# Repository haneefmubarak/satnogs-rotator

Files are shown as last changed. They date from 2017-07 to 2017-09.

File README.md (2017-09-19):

# SatNOGS Rotator

Hardware for SatNOGS Rotator. This repository includes all needed source files for 3D printed (and other) parts of SatNOGS Rotator.

## Documentation

More information can be found in our [documentation](http://satnogs.org/documentation/hardware/), or our [wiki](https://wiki.satnogs.org).

## Repository policy
SatNOGS hardware repositories only track source design files. All needed derivative files (e.g. stl, grb etc) for production are created per release, packaged in an archive and uploaded linked to a  [release](https://gitlab.com/librespacefoundation/satnogs/satnogs-rotator/tags).

Each major release (x.0.0) is branched out of master. Subsequent fixes (minor or not) are commited on those branches and tagged accordingly.

Master branch is most times under active development, so expect things to break. For production ready and previous releases source files check tags and branches.

## Contribute

The main repository lives on [Gitlab](https://gitlab.com/librespacefoundation/satnogs/satnogs-rotator) and all Merge Request should happen there.

## License

&copy; 2014-2015 [Libre Space Foundation](http://librespacefoundation.org).

Licensed under the [CERN OHLv1.2](LICENSE).

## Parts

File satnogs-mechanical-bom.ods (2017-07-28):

Part | Description | Distributor | Qty For 1 Rotator | Price Per Unit Small QNT (euro) | Total Price | Printing Time (min) Per 1 part | Price Per Unit Large QNT (euro) | Total price | Comments | QTY 30 kits
axis_side.stl | Axis side, 3D printed | - | 4 | 0.5 | 2 | 110 | 0.7 | 2.8 |  | 116
switch_endstop_holder.stl | Mount for mechanichal endstop, 3D printed | - | 2 | 0.5 | 1 | 4 | 0.7 | 1.4 |  | 0
ball_bearing_housing.stl | Ball bearing housing, 3D printed | - | 4 | 0.5 | 2 | 46 | 0.7 | 2.8 |  | 116
axis_spacer.stl | Axis spacer, 3D printed | - | 2 | 0.5 | 1 | 15 | 0.7 | 1.4 |  | 61
axis_gear.stl | Axis gear (Worm wheel), 3D printed | - | 2 | 0.5 | 1 |  | 0.7 | 1.4 |  | 46
axis_gear_flange.stl | Flange for mounting axis gear, 3D printed | - | 2 | 0.5 | 1 |  | 0.7 | 1.4 |  | 0
axis_gear_as5601.stl | Gear for encoder (on-axis), homing ring mount and axis flange 3D printed | - | 2 | 0.5 | 1 | 40 | 0.7 | 1.4 |  | 0
homing_ring.stl | Homing ring, 3D printed | - | 2 | 0.5 | 1 | 5 | 0.7 | 1.4 |  | 0
worm_gear.stl | Worm gear, 3D printed | - | 2 | 0.5 | 1 | 105 | 0.7 | 1.4 |  | 0
worm_mount.stl | Worm mount, 3D printed | - | 2 | 0.5 | 1 | 84 | 0.7 | 1.4 | Printing together | 56
worm_mount_mirror.stl | Worm mount mirror, 3D printed | - | 2 | 0.5 | 1 | 84 | 0.7 | 1.4 | Printing together | 57
motor_mount_flange.stl | DC Motor mount flange, 3D printed | - | 2 | 0.5 | 1 | 21 | 0.7 | 1.4 |  | 57
motor_mount_plastic.stl | Motor mount, 3D printed | - | 2 | 0.5 | 1 | 43 | 0.7 | 1.4 |  | 0
dc-motor-cup.stl | for DC motor, 3D printed | - | 2 | 0.5 | 1 | 12 | 0.7 | 1.4 | optional | 0
dc-motor-heatshrink.stl | for DC motor, 3D printed | - | 2 | 0.5 | 1 | 12 | 0.7 | 1.4 | optional | 0
Heat-shrink | Length 45mm, Diameter 35mm | [3] (http://www.ebay.com/itm/BLACK-HEATSHRINK-2-1-TUBE-TUBING-SLEEVE-SLEEVING-HEAT-SHRINK-WRAP-CABLE-13-80MM-/222200367492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) | 2 | - | 2.2 | - | - | 2.2 | optional | 0
t_slot20_100.fcstd | T slot 20x20 B-type L100 | [1] (http://www.motedis.com/shop/Slot-profiles/Profile-20-B-Type-slot-6/Profile-20x20-B-type-slot-6::1.html) | 18 | 0.294 | 5.292 | - | 0.3 | 5.4 |  | 0
t_slot20_160.fcstd | T slot 20x20 B-type L160 | [1] (http://www.motedis.com/shop/Slot-profiles/Profile-20-B-Type-slot-6/Profile-20x20-B-type-slot-6::1.html) | 8 | 0.4704 | 3.7632 | - | 0.47 | 3.76 |  | 0
axis_pipe_40mm.fcstd | Aluminum pipe 40x1.5mm L320mm | [1] (http://www.motedis.com/shop/Semi-finished-products/Circular-tube-anodized-DIN-6060/Circular-tube-40x15-anodized::1066.htmll) | 2 | 1.3984 | 2.7968 | - | 0.56 | 1.12 |  | 60
cover_bottom.pdf | Part for weather proof box | - | 1 | 2 | 2 | - | 1.6 | 1.6 |  | 0
cover_side.pdf | Part for weather proof box | - | 1 | 2 | 2 | - | 1.6 | 1.6 |  | 0
cover_side_mirror.pdf | Part for weather proof box | - | 1 | 2 | 2 | - | 1.6 | 1.6 |  | 0
cover_top.pdf | Part for weather proof box | - | 1 | 2 | 2 | - | 1.6 | 1.6 |  | 0
rain_cover_tube.stl | Part for weather proof box, 3D printed | - | 2 | 0.5 | 1 |  | 0.7 | 1.4 |  | 0
Aluminum blind Domed rivets, DIN 7337A | Form A, 2.4x6 | - | 11 | ? | ? | - | ? | ? |  | 0
Phillips Rounded Head Screws for Sheet Metal | 18-8 Stainless Steel, Number 2 Size, 1/8" Long, type A/AB | - | 11 | ? | ? | - | ? | ? | [Mcmaster-carr] (https://www.mcmaster.com/#92470a089/=16a5gwu) | 0
off_axis_gear_as5601.stl | Gear for encoder (off-axis), 3D printed | - | 2 | 0.5 | 1 | 23 | 0.7 | 1.4 |  | 0
holder_as5601.stl | Mount for encoder, 3D printed | - | 2 | 0.5 | 1 | 25 | 0.7 | 1.4 |  | 0
as5601_case_1.stl | Part #1 of encoder case, 3D printed | - | 2 | 0.5 | 1 |  | 0.7 | 1.4 |  | 0
as5601_case_2.stl | Part #2 of encoder case, 3D printed | - | 2 | 0.5 | 1 |  | 0.7 | 1.4 |  | 0
as5601_case_3.stl | Part #3 of encoder case, 3D printed | - | 2 | 0.5 | 1 |  | 0.7 | 1.4 |  | 0
as5601_magnet_base.stl | Base for magnet | - | 2 | 0.5 | 1 |  | 0.7 | 1.4 |  | 0
encoder_magnet.fcstd | For encoder, Diametric Magnet NdFeB, Grade N35, D6x2.5mm | [3] (https://pt.aliexpress.com/item/100-pcs-NdFeB-Magnet-Disc-Dia-6x2-5-mm-0-236-Diametrically-Magnetized-Strong-Magnet-Neodymium/32639986878.html) | 2 | 0.2 | 0.4 | - | 0.2 | 0.4 | Datasheet (http://ams.com/eng/Products/Position-Sensors/Magnets/AS5000-MD6H-3) | 60
electronics_case.fcstd | Full metal box for electronics, (120x100x35)mm | [2] (http://grobotronics.com/project-box-120x100x35mm-aluminium.html) | 1 | 7.5 | 7.5 | - | 7.5 | 7.5 | B023/BS-023 - Datasheet (http://grobotronics.com/images/companies/1/ALU-BS23.pdf) | 0
electronics_case_pcb_mount.stl | PCB mount, 3D printed | - | 2 | 0.5 | 1 | 5 | 0.7 | 1.4 |  | 0
cable_gland | Cable Gland for electronics box | [3] (http://www.ebay.com/itm/5Pcs-5X-Connector-Gland-3-6-5Mm-Dia-Cable-Waterproof-Pg7-Black-Plastic-Ic-New-M-/282283689551) | 4 | 0.17 | 0.68 | - | 0.17 | 0.68 | NG9511 - Datasheet (http://www.mouser.com/ds/2/55/hb9511-30841.pdf) | 0
M5 Threaded Rod | for axis of worm gear, L100mm | - | 2 | 1 | 2 | - | 1 | 2 |  | OK
M5 Hex Nut DIN934 | for axis of worm gear | - | 4 | 0.02 | 0.08 | - | 0.02 | 0.08 |  | OK
M5 Washer DIN125 | for axis of worm gear, OD:10mm | - | 6 | 0.012 | 0.072 | - | 0.012 | 0.072 |  | 0
Inner bracket 20 steel B-Type slot 6 | for t slots | [1] (http://www.motedis.com/shop/Slot-profiles-accessories/Accessoiries-20-B-Typ-slot-6/Inner-bracket-20-steel-B-Type-slot-6::562.html) | 44 | 0.9 | 39.6 | - | 0.5 | 22 |  | 0
M4 T-nut B-type slot 6 | for t slots, electronics box, cover box, encoder mounts and motor mount | [1] (http://www.motedis.com/shop/Slot-profiles-accessories/Accessoiries-20-B-Typ-slot-6/T-nut-B-type-slot-6::555.html) | 36 | 0.5 | 18 | - | 0.18 | 6.48 |  | 0
M4 Head Cap Screw L10 DIN912 | for t slots, electronics box, cover box encoder mount and motor mount | - | 36 | 0.04 | 1.44 | - | 0.04 | 1.44 |  | OK
M4 Head Cap Screw L15 DIN912 | for metal box with electroniics | - | 2 | 0.04 | 0.08 | - | 0.04 | 0.08
M4 Head Cap Screw L20 DIN912 | for ball bearing housing | - | 12 | 0.06 | 0.72 | - | 0.06 | 0.72 |  | OK
M4 Head Cap Screw L25 DIN912 | for ball bearing housing - end stop mount, axis gear | - | 12 | 0.06 | 0.72 | - | 0.06 | 0.72 |  | 0
M4 Hex Nut DIN934 | for ball bearing housing and axis gear | - | 28 | 0.014 | 0.392 | - | 0.014 | 0.392 |  | OK
M4 Washers DIN125 | general, OD:9mm | - | 40 | 0.012 | 0.48 | - | 0.012 | 0.48 |  | OK
M3 Hex Nut DIN934 | For encoder, axis gears and DC motor | - | 28 | 0.012 | 0.336 | - | 0.012 | 0.336 |  | OK
M3 Washers DIN125 | for encoder and DC motor, OD: 7mm | - | 10 | 0.012 | 0.12 | - | 0.012 | 0.12 |  | OK
M3 Set Screw L10 DIN916 or DIN914 | for axis gear as5601 and axis gear flange | - | 16 | 0.04 | 0.64 | - | 0.04 | 0.64 |  | OK
M3 Head Cap Screw L6 DIN912 | for stepper motor, DC motor mount flange | - | 8 | 0.03 | 0.24 | - | 0.03 | 0.24 |  | OK
M3 Head Cap Screw L12 DIN912 | for DC motor mount | - | 6 | 0.03 | 0.18 | - | 0.03 | 0.18 |  | OK
M3 Flat-Head Socket Cap Screw L10, DIN7991 | for encoder magnet base, off-axis encoder gear, encoder mount | - | 8 | 0.05 | 0.4 | - | 0.05 | 0.4 |  | 0
M3 Female to Female Threaded Hex Standoff L10 | for encoder axis (for off-axis gear) | [2] (http://grobotronics.com/stand-off-plastic-f-f-10mm.html) | 2 | 0.18 | 0.36 | - | 0.1 | 0.2 |  | 0
M2 Screw L16, DIN912 or DIN7985 | for encoder case and endstop switch mount | - | 12 | 0.05 | 0.6 | - | 0.05 | 0.6 |  | 0
M2 Hex Nut DIN943 | for encoder case and endstop switch mount | - | 12 | 0.014 | 0.168 | - | 0.05 | 0.6 |  | 0
M2 Washers DIN125 | for encoder case and endstop switch mount, OD: 5mm | - | 12 | 0.012 | 0.144 | - | 0.05 | 0.6 |  | 0
Ball Bearing 6008ZZ | for main axis | - | 4 | 5 | 20 | - | 2 | 8 |  | 114
Ball Bearing 625ZZ | for worm gear axis | - | 4 | 0.8 | 3.2 | - | 0.45 | 1.8 |  | 118
Ball Bearing 623ZZ | for encoder axis (for off-axis gear) | - | 2 | 0.8 | 1.6 | - | 0.45 | 0.9 |  | 0
Timing Pulley GT2, 20 Tooth | 6mm Belt, 6mm(DC motor)/5mm(Stepper motor) Bore | [2] (http://grobotronics.com/aluminum-gt2-timing-pulley-6mm-belt-20-tooth-5mm-bore.html) | 2 | 2.6 | 5.2 | - | 1.8 | 3.6 |  | 0
Timing Pulley GT2, 36 Tooth | 6mm Belt, 5mm Bore | [2] (http://grobotronics.com/aluminum-gt2-timing-pulley-6mm-belt-36-tooth-5mm-bore.html) | 2 | 4.2 | 8.4 | - | 2.9 | 5.8 |  | 0
Timing Belt GT2, 158mm | 6mm Wide | [2] (http://grobotronics.com/timing-belt-gt2-158mm.html) | 2 | 1.5 | 3 | - | 1 | 2 |  | 0
 |  |  |  | Total | 163.804 |  |  | 122.94 | Exclude Shipping Costs

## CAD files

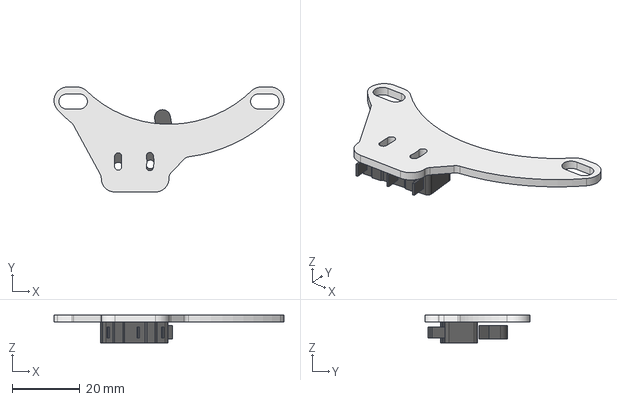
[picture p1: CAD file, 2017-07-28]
assemblies/switch_endstop_assembly.fcstd
67.9 x 31.0 x 8.20 mm
switch_endstop_holder_01
switch_SS0505_01

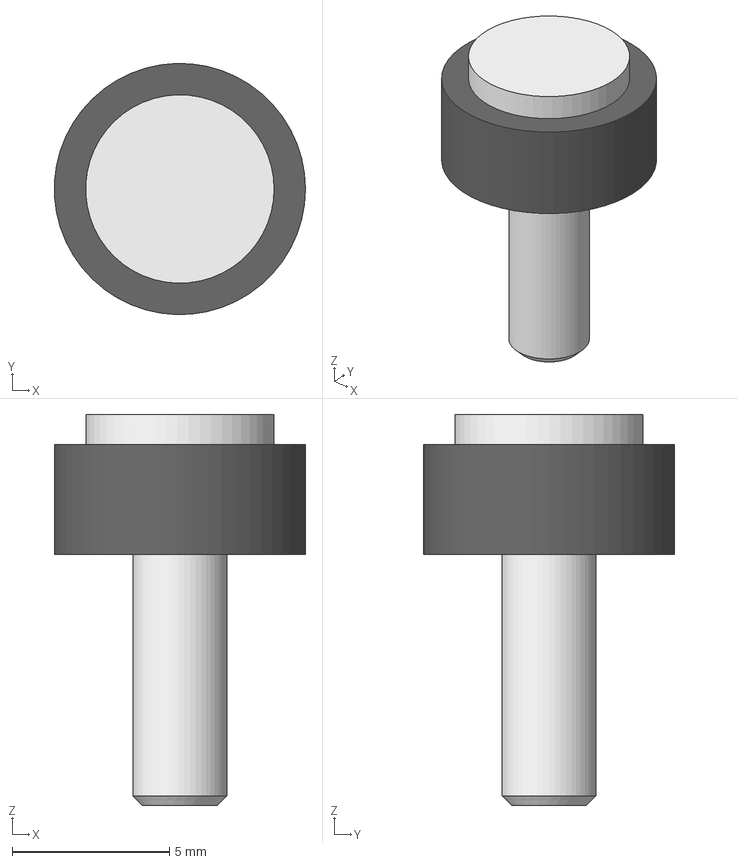
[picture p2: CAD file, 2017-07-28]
electronics/as5601_axis_assembly.fcstd
7.99 x 8.00 x 12.4 mm
as5601_magnet_base_01
flat_head_screw_M3L10_DIN7991_01
encoder_magnet_01

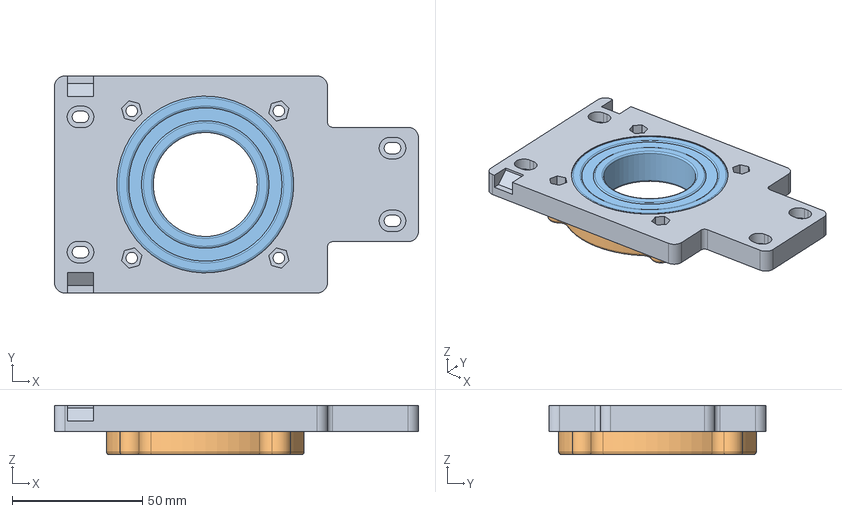
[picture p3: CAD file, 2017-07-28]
assemblies/axis_side_assembly.fcstd
140.0 x 83.5 x 19.0 mm
axis_side_01
ball_bearing_housing_01
ball_bearing_6008ZZ_01

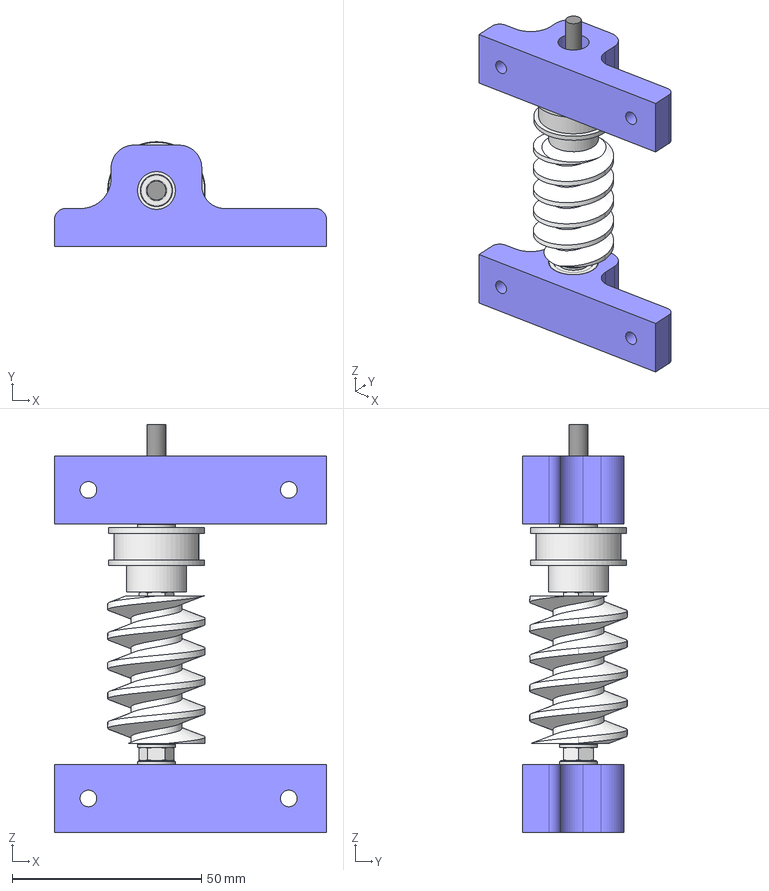
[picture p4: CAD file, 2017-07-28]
assemblies/worm_gear_assembly.fcstd
72.0 x 27.7 x 107.9 mm
worm_mount_01
ball_bearing_625ZZ_01
worm_axis_01
washer_M5_DIN125_01
nut_M5_DIN934_01
washer_M5_DIN125_02
worm_gear_01
nut_M5_DIN934_02
timing_pulley_gt2_36T_01
washer_M5_DIN125_03
ball_bearing_625ZZ_02
worm_mount_mirror_01

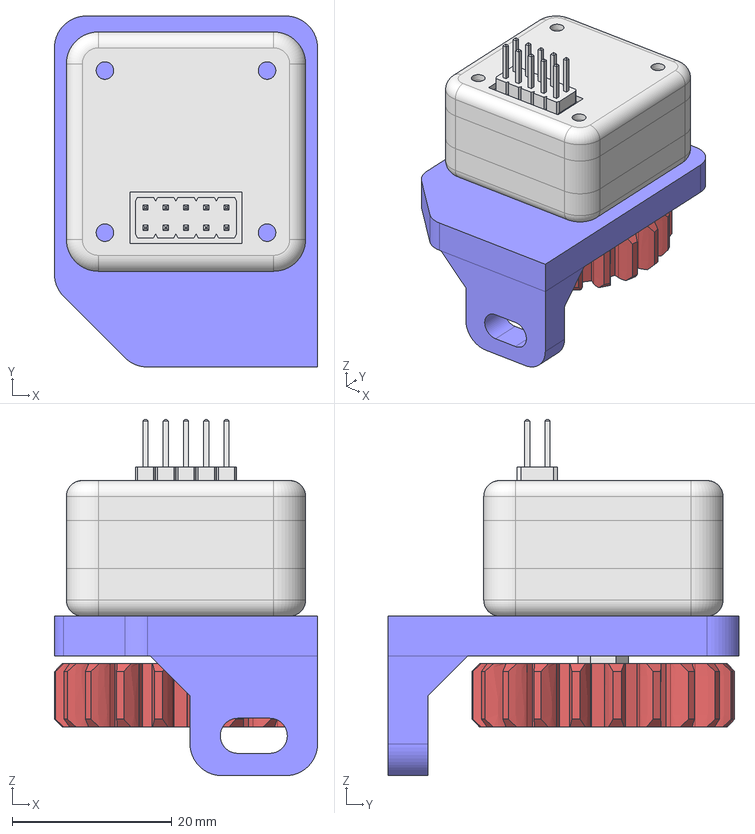
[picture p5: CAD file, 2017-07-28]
assemblies/as5601_mount_assembly.fcstd
33.0 x 44.0 x 44.7 mm
holder_as5601_01
as5601_assembly_01
standoff_hex_nylon_M3_L10_ff_01
off_axis_gear_as5601_01

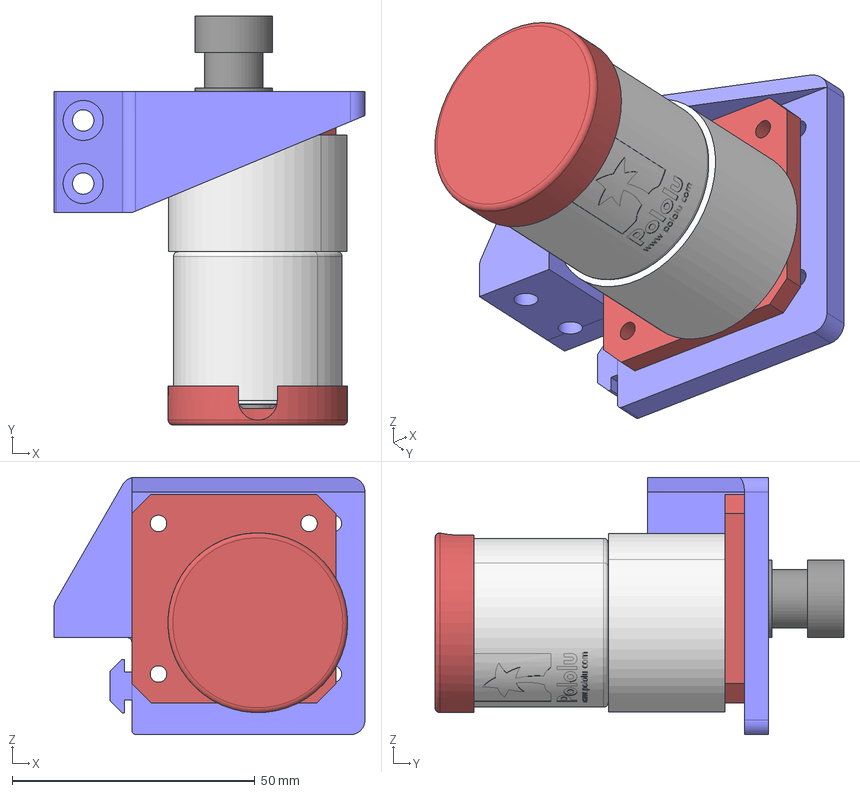
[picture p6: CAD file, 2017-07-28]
assemblies/dc_motor_assembly.fcstd
64.0 x 84.2 x 53.0 mm
motor_mount_plastic_01
motor_mount_flange_01
dc_motor_50_1_01
dc_motor_cup_01
dc_motor_heatshrink_01
timing_pulley_gt2_20T_01

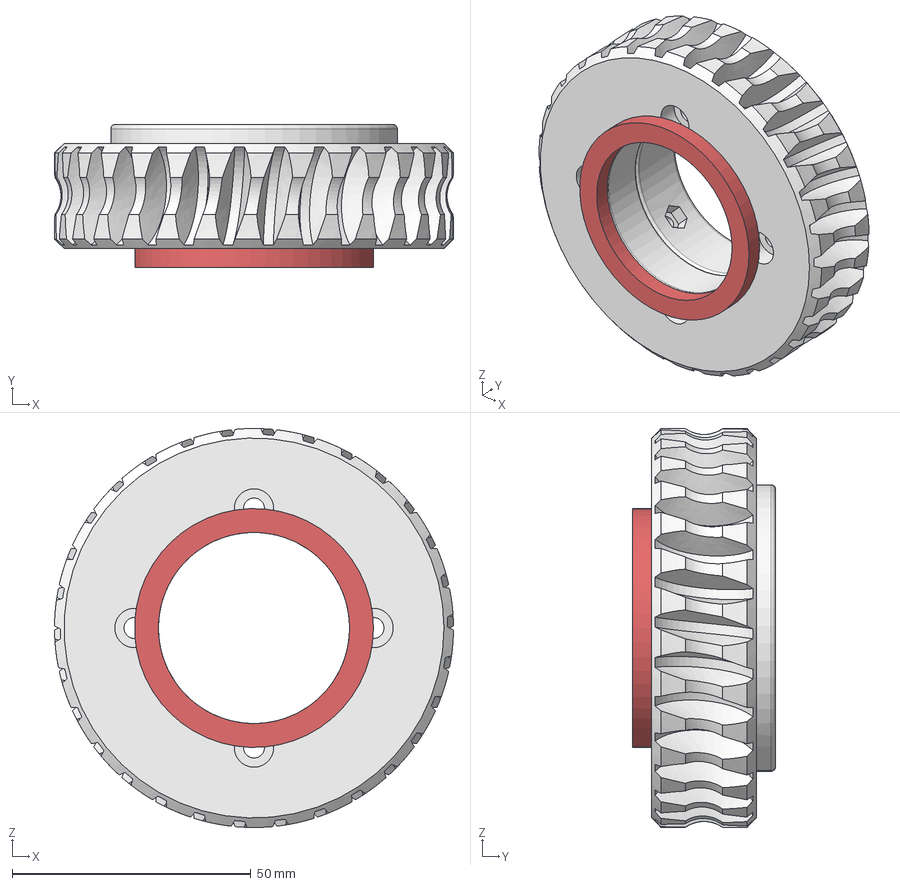
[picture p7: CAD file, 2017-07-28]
assemblies/axis_gear_assembly.fcstd
83.5 x 30.0 x 83.5 mm
axis_gear_01
axis_gear_flange_01
axis_spacer_01

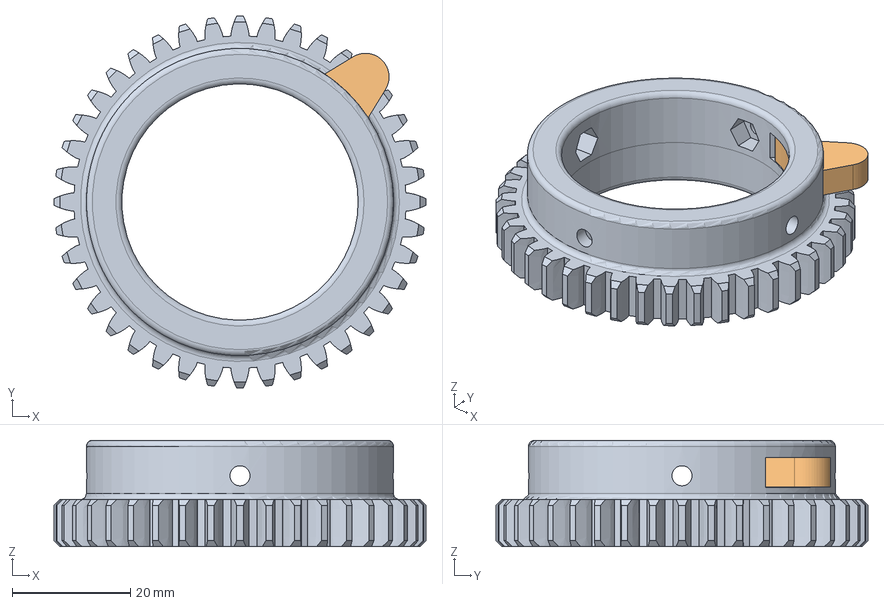
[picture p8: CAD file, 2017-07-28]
assemblies/axis_flange_assembly.fcstd
63.0 x 63.0 x 18.0 mm
axis_gear_as5601_01
homing_ring_01

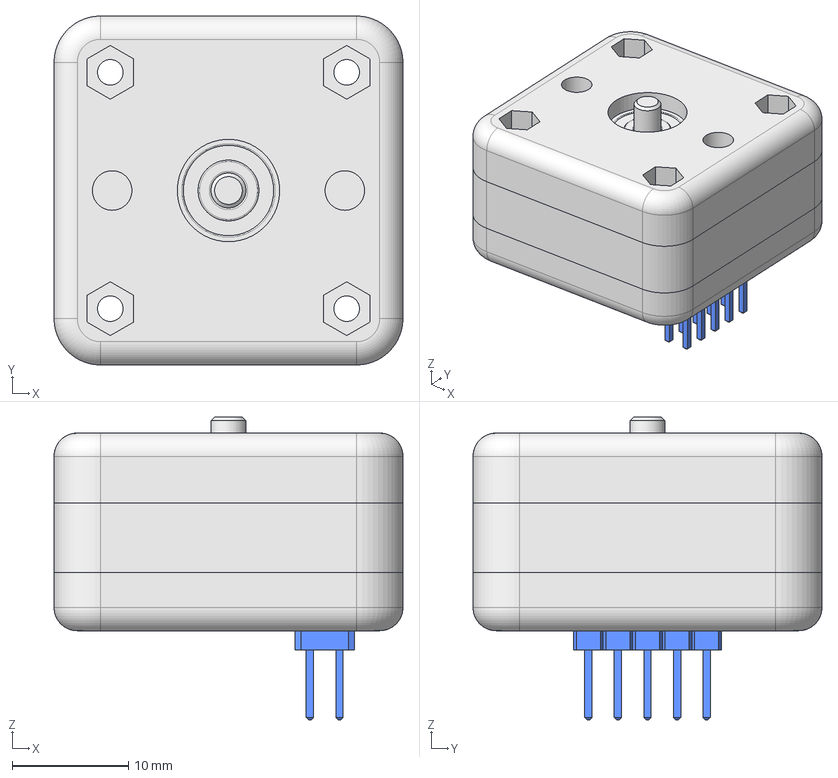
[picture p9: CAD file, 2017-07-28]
electronics/as5601_assembly.fcstd
30.0 x 30.0 x 26.0 mm
encoder_case_1_01
encoder_as5601_01
encoder_case_2_01
ball_bearing_623ZZ_01
encoder_case_3_01
washer_M3_DIN125_01
as5601_axis_assembly_01

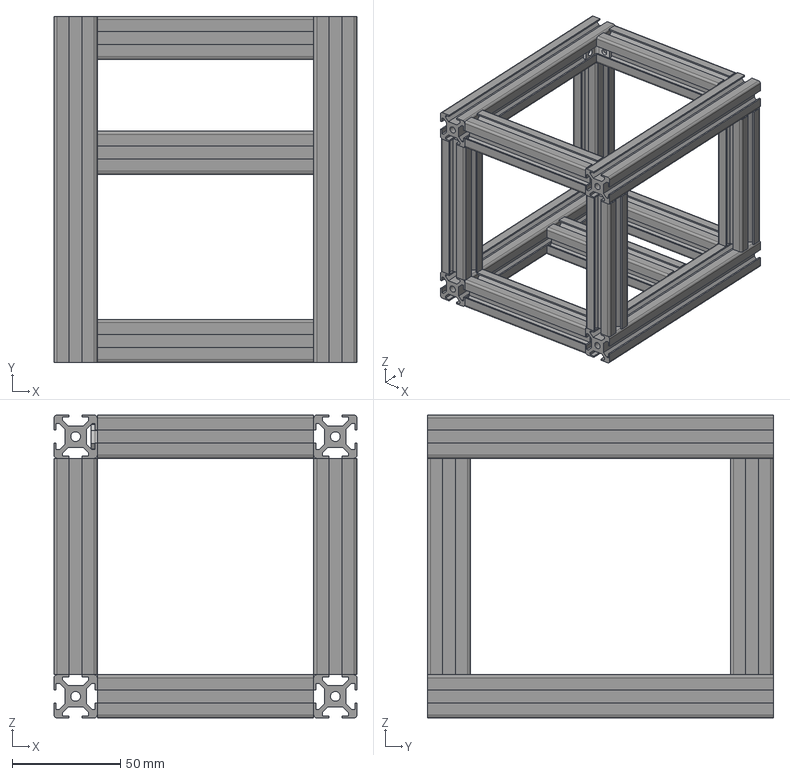
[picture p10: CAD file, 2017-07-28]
assemblies/frame.fcstd
140.0 x 160.0 x 140.0 mm
t_slot20_100_01
t_slot20_160_01
t_slot20_160_02
t_slot20_100_02
t_slot20_100_03
t_slot20_100_04
t_slot20_100_05
t_slot20_100_06
t_slot20_160_03
t_slot20_160_04
t_slot20_100_07
t_slot20_100_08
t_slot20_100_09
Inner_bracket_20_steel_B_Type_slot6_01
Inner_bracket_20_steel_B_Type_slot6_01001

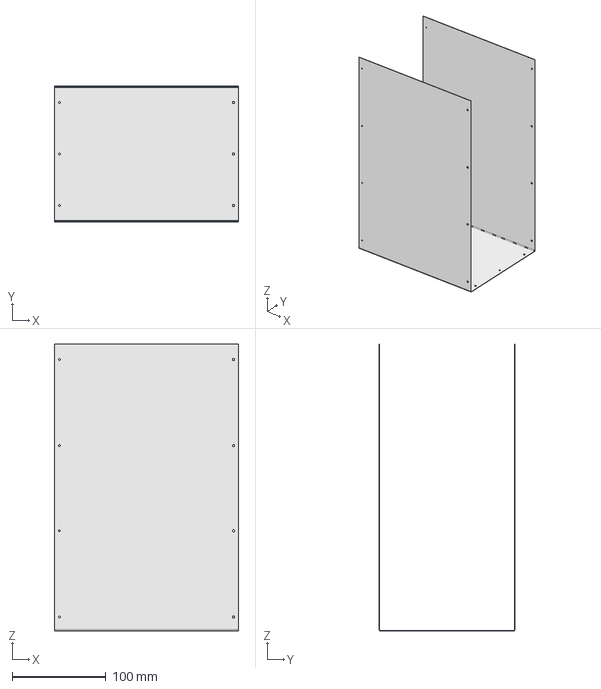
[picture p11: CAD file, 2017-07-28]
cover/cover_top.fcstd
197.0 x 145.0 x 306.5 mm

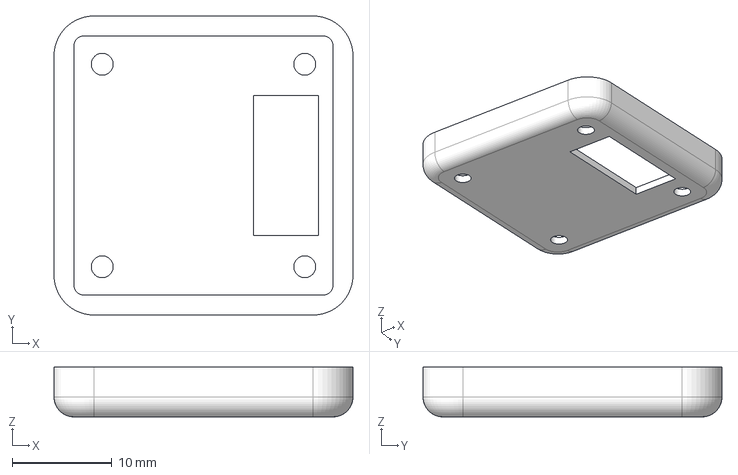
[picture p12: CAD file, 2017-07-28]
electronics/as5601_case_1.fcstd
30.0 x 30.0 x 5.00 mm

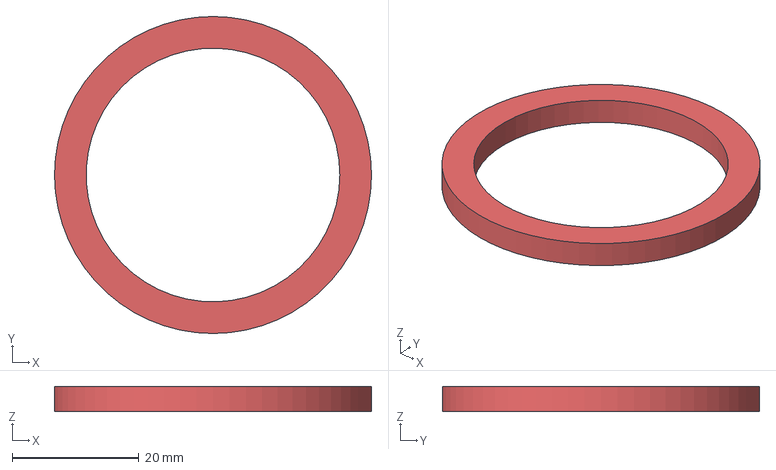
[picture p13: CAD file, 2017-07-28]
rotator_parts/axis_spacer.fcstd
50.0 x 50.0 x 4.00 mm

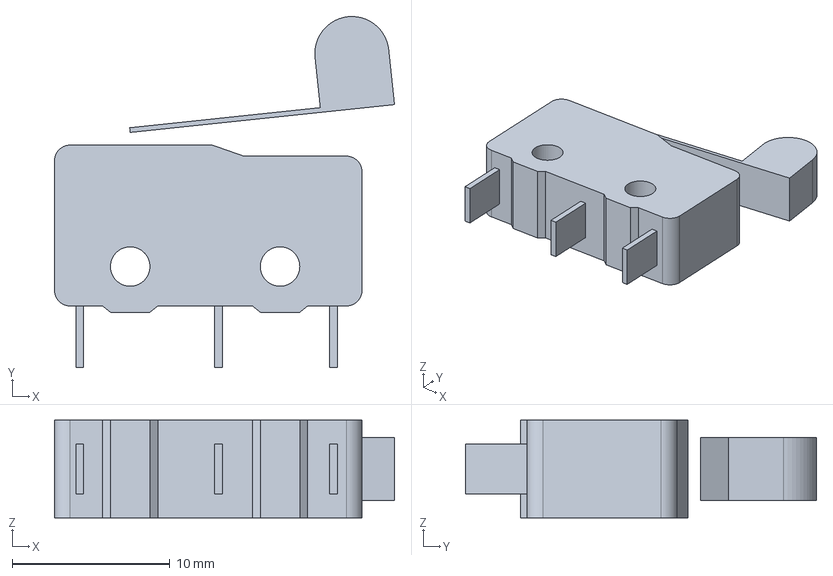
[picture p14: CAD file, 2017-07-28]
shared/switch_SS0505.fcstd
21.6 x 22.2 x 6.20 mm

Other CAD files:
cover/cover_side_mirror.fcstd
rotator_parts/worm_mount.fcstd
shared/ball_bearing_623ZZ.fcstd
cover/cover_bottom.fcstd
cover/cover_side.fcstd
cover/rain_cover_tube.fcstd
electronics/as5601_case_2.fcstd
electronics/as5601_case_3.fcstd
electronics/as5601_magnet_base.fcstd
electronics/as5601_pcb.fcstd
electronics/electronics_case.fcstd
electronics/electronics_case_bottom.fcstd
electronics/electronics_case_pcb_mount.fcstd
electronics/electronics_case_top.fcstd
electronics/encoder_magnet.fcstd
electronics/holder_as5601.fcstd
electronics/off_axis_gear_as5601.fcstd
rotator_parts/axis_gear_flange.fcstd
rotator_parts/axis_pipe_40mm.fcstd
rotator_parts/axis_side.fcstd
rotator_parts/ball_bearing_housing.fcstd
rotator_parts/dc_motor_cup.fcstd
rotator_parts/dc_motor_heatshrink.fcstd
rotator_parts/homing_ring.fcstd
rotator_parts/motor_mount_flange.fcstd
rotator_parts/motor_mount_plastic.fcstd
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
